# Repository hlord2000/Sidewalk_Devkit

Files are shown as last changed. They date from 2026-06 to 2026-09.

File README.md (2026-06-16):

# Sidewalk Devkit

KiCad hardware design for a compact Nordic Semiconductor devkit built around an
`nRF54L15` target, `nPM1300` power management, and an `SX1262` sub-GHz radio
front end.

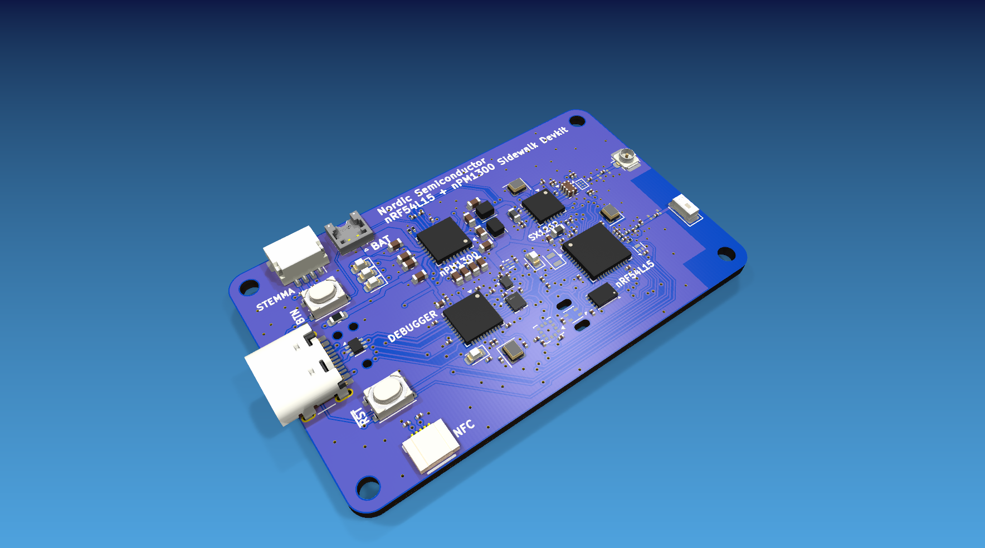
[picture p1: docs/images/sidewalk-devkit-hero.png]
Sidewalk Devkit 3D render


## Hardware

- `nRF54L15-QFAA` target SoC with external `32 MHz` and `32.768 kHz` crystals.
- `nPM1300-QEAA` PMIC for USB/battery power management, charging, and status LEDs.
- `SX1262IMLTRT` sub-GHz transceiver with RF switch/filter network, U.FL, and chip antenna footprints.
- On-board `nRF52833-QDXX` debug helper with USB, SWD, UART, and level-translated target boundary.
- USB-C input with ESD protection and a 1 A fuse.
- Battery connector, reset/user buttons, and board-edge debug/test access.
- `STEMMA QT` I2C expansion connector.
- `SHT4x` humidity/temperature sensor, `ADXL367` accelerometer, and `ZD25WQ16CEIGR` QSPI flash.
- NFC connector footprint and user/status LEDs.

## Board

| Property | Value |
| --- | --- |
| KiCad version | 10.x project files |
| Board revision | `0.1` |
| Size | `55 mm x 34 mm` |
| Stackup | 6 copper layers, 1.6 mm board thickness |
| Minimum track / clearance | `0.127 mm / 0.127 mm` |
| Minimum drill | `0.200 mm` |

## Passed Qualification Tests

- Flashing the `nRF54L15` target from the on-board `nRF52833` debug helper.
- RTT logging.
- UART logging.
- BLE validation.
- NFC validation.
- Sensor and PMIC logging from `SHT40`, `ADXL367`, and `nPM1300`.
- `SX1262` radio operation in both FSK and LoRa modes.
- Sidewalk operation over all transports.

### Top

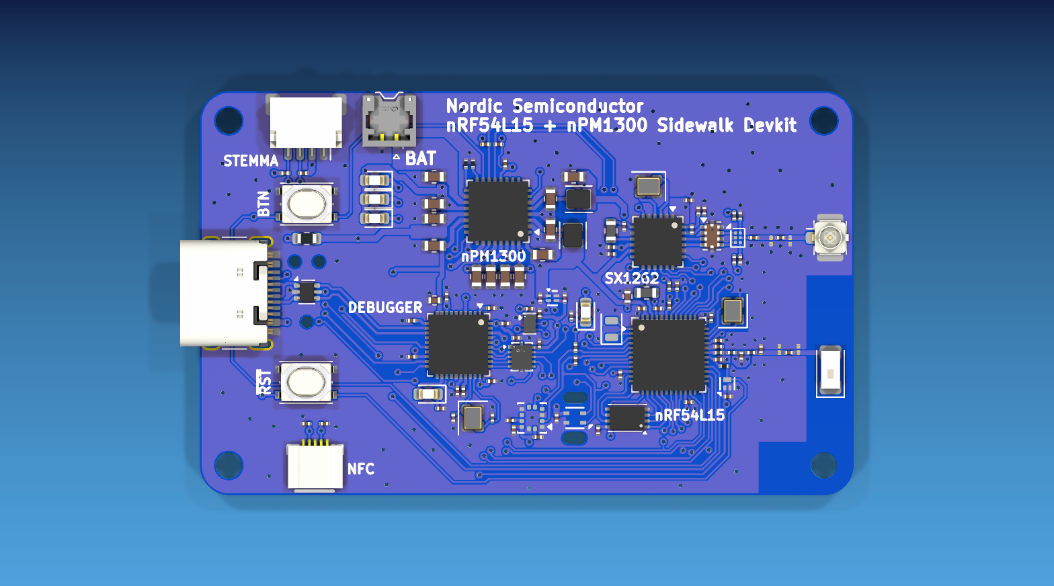
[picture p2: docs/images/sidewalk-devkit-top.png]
Sidewalk Devkit top render


### Bottom

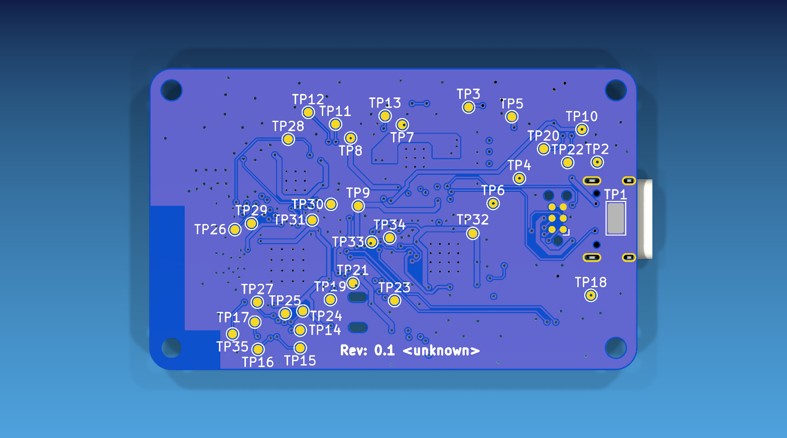
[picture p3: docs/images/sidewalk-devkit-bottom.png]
Sidewalk Devkit bottom render


## Schematic Structure

The design is split into hierarchical KiCad sheets:

- `sch/nRF54L15.kicad_sch` - target SoC, sensors, QSPI flash, STEMMA QT, NFC, and user IO.
- `sch/SX1262.kicad_sch` - sub-GHz radio, RF matching/filtering, antenna switch, and RF connectors.
- `sch/nPM1300.kicad_sch` - USB-C, battery input, PMIC rails, charger support, and PMIC LEDs.
- `sch/Debugger.kicad_sch` - on-board debug helper, target SWD/UART boundary, and level shifting.

## Repository Layout

```text
.
|-- Sidewalk_Devkit.kicad_pro   KiCad project
|-- Sidewalk_Devkit.kicad_sch   Top-level schematic
|-- Sidewalk_Devkit.kicad_pcb   PCB layout
|-- sch/                        Hierarchical schematic sheets
|-- lib/                        Local symbols, footprints, and 3D models
|-- docs/images/                README render images
|-- build/                      Local generated outputs, ignored by git
`-- debug_helper_parts.md       Notes for the debug-helper boundary parts
```

## Regenerating Outputs

The README images are rendered directly from the KiCad PCB:

```bash
mkdir -p docs/images

kicad-cli pcb render Sidewalk_Devkit.kicad_pcb \
  --output docs/images/sidewalk-devkit-hero.png \
  --width 1800 --height 1000 \
  --background opaque --quality high --perspective \
  --rotate '-35,0,35' --zoom 0.84

kicad-cli pcb render Sidewalk_Devkit.kicad_pcb \
  --output docs/images/sidewalk-devkit-top.png \
  --width 1600 --height 900 \
  --side top --background opaque --quality high --zoom 1.12

kicad-cli pcb render Sidewalk_Devkit.kicad_pcb \
  --output docs/images/sidewalk-devkit-bottom.png \
  --width 1600 --height 900 \
  --side bottom --background opaque --quality high --zoom 1.12
```

Useful local exports:

```bash
mkdir -p build

kicad-cli sch export pdf Sidewalk_Devkit.kicad_sch \
  --output build/schematic.pdf

kicad-cli pcb export step Sidewalk_Devkit.kicad_pcb \
  --output build/board.step

kicad-cli sch export bom Sidewalk_Devkit.kicad_sch \
  --output build/bom.csv \
  --fields Reference,Value,Footprint,QUANTITY,DNP \
  --group-by Value,Footprint
```

The custom EasyEDA-derived footprints and 3D models live under `lib/`. STEP
export may still warn if a local KiCad installation does not include every
referenced stock KiCad 3D model.

Run design checks before fabrication or release:

```bash
mkdir -p build
kicad-cli sch erc Sidewalk_Devkit.kicad_sch --output build/erc.rpt
kicad-cli pcb drc Sidewalk_Devkit.kicad_pcb --output build/drc.rpt
```

## License

This hardware design is licensed under the CERN Open Hardware Licence Version 2
- Permissive. See [LICENSE](LICENSE).

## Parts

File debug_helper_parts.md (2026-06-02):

# USB Debug Helper Parts

Date: 2026-05-28

## Chosen MCU

Use `STM32G0B1KBU6`.

- LCSC: `C5159549`
- Package: `UFQFPN-32 5x5`
- Function: USB-powered Zephyr debug helper MCU
- Relevant fit: Zephyr `SOC_STM32G0B1XX`, USB FS from HSI48, UART, enough GPIO for SWD bit-bang
- Parts MCP availability: 325 in stock, extended part, about `$3.02` qty 1 / `$2.55` qty 10

## Target Boundary Interface

Use a `TXU0204RUTR` fixed-direction translator, a dedicated `TXU0101DRYR`
SWDIO output translator, and a switched copy of the target `VTREF`.

SWCLK is one-way helper-to-target. SWDIO is bidirectional at the protocol level,
but this circuit handles it as two one-way legs tied together on the target
side: a target-to-helper read path and a separately enabled helper-to-target
drive path. That matches Zephyr's `dio-gpios`, `dout-gpios`, and `dnoe-gpios`
model.

One `TXU0204` cannot safely do the whole boundary by itself because its single
`OE` would also enable the helper-to-target SWDIO driver during target reads.
Use `TXU0101DRYR` as the independently enabled SWDIO output buffer.

### Recommended Parts

`U_LS_MAIN = TXU0204RUTR`

- LCSC: `C5217875`
- Package: `UQFN-12 1.7x2`
- Quantity: `1`
- Function: dual-supply 4-bit fixed-direction translator, two channels A to B and two channels B to A
- Relevant fit: SWCLK, UART TX, UART RX, and SWDIO read path
- Parts MCP availability: 1354 in stock, extended part, about `$0.90` qty 1 / `$0.78` qty 10

`U_LS_SWDIO_OUT = TXU0101DRYR`

- LCSC: `C5217869`
- Package: `SON-6 1x1.4`
- Quantity: `1`
- Function: dedicated one-channel translator used as a separately enabled SWDIO output buffer
- Relevant fit: helper-driven SWDIO output; high-Z whenever Zephyr's `dnoe-gpios` is inactive
- Parts MCP availability: 242 in stock, extended part, about `$0.50` qty 1 / `$0.43` qty 10

`U_VTREF_SW = TPS22917DBVR`

- LCSC: `C2681320`
- Package: `SOT-23-6`
- Quantity: `1`
- Function: low-leakage load switch for `TARGET_VTREF_NPM` to `VTREF_DBG`
- Relevant fit: 1 V to 5.5 V input, active-high ON, reverse-current blocking, low off current
- Parts MCP availability: 19645 in stock, extended part, about `$0.31` qty 1 / `$0.23` qty 50

`Q_RESET = 2N7002`

- LCSC: `C8545`
- Package: `SOT-23`
- Quantity: `1`
- Function: debugger-controlled open-drain `nRESET` pull-down
- Parts MCP availability: basic part, about 1.63M in stock, about `$0.014` qty 1

## Power And Leakage Rule

The helper and target stay separate power domains.

- `DBG_3V3`: helper-side rail from the helper USB port; powers the STM32 and all translator `VCCA` pins.
- `TARGET_VTREF_NPM`: target IO rail from the nPM1300; do not connect this directly to translator `VCCB`.
- `VTREF_DBG`: switched copy of `TARGET_VTREF_NPM`; powers translator `VCCB` only while helper USB is present and the helper firmware enables the boundary.

Wire `TPS22917DBVR` as:

- `VIN`: `TARGET_VTREF_NPM`
- `VOUT`: `VTREF_DBG`
- `ON`: `DBG_BOUNDARY_EN` from the helper, with about `100 kOhm` pulldown to ground
- `CT`: open, unless a slower `VTREF_DBG` rise is wanted
- `QOD`: connect to `VOUT` for fast `VTREF_DBG` discharge, or leave open for the slowest discharge

When helper USB is unplugged, `DBG_BOUNDARY_EN` is low, `VTREF_DBG` is off, and the target rail is not feeding translator supply current. The remaining target-side current is only pin leakage into unpowered translator I/O plus the load switch off leakage.

Worst-case leakage estimate with helper USB absent:

- `TXU0204` / `TXU0101` Ioff max: `2.5 uA` per A/B pin over `-40 C` to `125 C`
- Target-connected translator pins: `SWCLK`, target `UART_RX`, target `UART_TX`, `SWDIO_IN`, `SWDIO_OUT` = `5` pins
- Translator pin leakage budget: about `12.5 uA` worst case across temperature
- `TPS22917` shutdown current: `250 nA` max to `105 C`; reverse leakage is `1 uA` max
- Add the selected reset MOSFET's off leakage from its own datasheet if reset leakage is critical

Typical leakage should be much lower, but the guaranteed worst-case number is what should be used for battery-life budgeting.

Add local decoupling: `100 nF` from each translator `VCCA` to ground, `100 nF` from each translator `VCCB` to ground, and `100 nF` to `1 uF` on `VTREF_DBG` after the load switch.

## Signal Mapping

Define side A as the STM32 debug helper and side B as the nRF54L15 target.
Helper and target grounds must be common at the debug boundary.

`U_LS_MAIN = TXU0204RUTR`

- `VCCA`: `DBG_3V3`
- `VCCB`: `VTREF_DBG`
- `OE`: `DBG_BOUNDARY_EN`, active high; add about `100 kOhm` pulldown to ground
- `A1 -> B1Y`: `DBG_SWCLK` to `TARGET_SWDCLK`
- `A2 -> B2Y`: `DBG_UART_TX` to `TARGET_UART_RX`
- `B3 -> A3Y`: `TARGET_UART_TX` to `DBG_UART_RX`
- `B4 -> A4Y`: `TARGET_SWDIO` to `DBG_SWDIO_IN`

If `U_LS_MAIN.OE` stays high while Zephyr has the SWD port off, add a weak
pulldown around `100 kOhm` on `DBG_SWCLK` so the target clock does not float.
Firmware should also leave `DBG_SWCLK` low when idle.

`U_LS_SWDIO_OUT = TXU0101DRYR`

- `VCCA`: `DBG_3V3`
- `VCCB`: `VTREF_DBG`
- `A -> BY`: `DBG_SWDIO_OUT` to `TARGET_SWDIO`
- `OE`: `DBG_SWDIO_OE`, active high; add about `100 kOhm` pulldown to ground

The target `SWDIO` node intentionally connects to both `U_LS_MAIN.B4` and
`U_LS_SWDIO_OUT.BY`. `U_LS_MAIN.B4` is only the target-to-helper read path.
`U_LS_SWDIO_OUT.BY` is high-Z except when Zephyr is actively driving SWDIO.

`Q_RESET = 2N7002`

- Drain: `TARGET_nRESET`
- Source: ground
- Gate: `DBG_nRESET_DRIVE_LOW` from the STM32 through about `100 Ohm`
- Gate pulldown: about `100 kOhm` to ground
- Target reset pullup: to the target IO rail, normally about `10 kOhm`

This keeps reset open-drain. When helper USB is unplugged, the MOSFET gate is held low and the target reset pullup does not back-power the helper.

Consider `22` to `47 Ohm` series resistors near the translator outputs on `SWCLK` and `SWDIO_OUT` if routing is longer than a short local connection.

## Zephyr SWDP Notes

Use Zephyr's GPIO SWDP binding with separate SWDIO input and output:

- `clk-gpios`: `DBG_SWCLK`
- `dio-gpios`: `DBG_SWDIO_IN`
- `dout-gpios`: `DBG_SWDIO_OUT`
- `dnoe-gpios`: `DBG_SWDIO_OE` configured as `GPIO_ACTIVE_HIGH`
- `noe-gpios`: omit for the `TXU0204` shared main translator, or use only if you accept that it also gates UART
- `reset-gpios`: `DBG_nRESET_DRIVE_LOW`; choose the GPIO polarity so Zephyr's deasserted reset state drives the NMOS gate physically low
- `keep-reset-deasserted`: include this property if your Zephyr tree has it and you want the driver to actively hold reset released after `swdp_port_off()`

The `dnoe-gpios` name is historical in Zephyr; the driver drives it high while outputting SWDIO and low while reading. That maps directly to the active-high `OE` pin on `TXU0101DRYR`.

If `noe-gpios` is used, the driver drives it logical active while the SWD port is on and logical inactive while off. Do not connect it to `U_LS_MAIN.OE` unless it is acceptable for UART to disappear whenever Zephyr turns the SWD port off.

Reset polarity needs one board-level check because Zephyr trees differ here. With the NMOS reset pull-down above, the safe electrical state is gate low. The `100 kOhm` gate pulldown guarantees that state when helper USB is absent. In firmware, configure the GPIO polarity so Zephyr's deasserted reset state produces a physical low on `DBG_nRESET_DRIVE_LOW`.

## Rejected Shortcut

Do not use a passive or auto-direction level shifter for SWDIO. SWDIO is push-pull and turnaround-sensitive, and Zephyr already supports the explicit `dio-gpios` / `dout-gpios` / `dnoe-gpios` pattern. The `TXU0204` plus `TXU0101` split follows that pattern directly.

`SN74AXC4T774RSVR` is tempting because it is a tiny per-bit-direction translator, but it does not give a separate OE for only the SWDIO output channel. It is less clean with the stock Zephyr SWDP binding than the `TXU0101` output-enable path.

Do not try to use only one `TXU0204` for both SWDIO directions. Its single `OE` would enable the SWDIO output driver during reads and can fight the target.

A second `TXU0204` for `SWDIO_OUT` also works electrically, but it wastes three channels and more board area compared with `TXU0101DRYR`.

## Sources Checked

- Parts MCP: `STM32G0B1KBU6`, `TXU0204RUTR`, `TXU0101DRYR`, `TPS22917DBVR`, `2N7002`, `SN74AXC4T774RSVR`
- Local Zephyr tree: `stm32g0b1` USB/HSI48 support, `zephyr,swdp-gpio` binding, and `swdp_bitbang.c`
- TI TXU0204 / TXU0101 product pages and datasheets: active-high `OE`, 1.08 V to 5.5 V rails, VCC isolation, and Ioff partial-power-down
- TI TPS22917 datasheet/product page: active-high ON, ultra-low shutdown current, and reverse-current blocking

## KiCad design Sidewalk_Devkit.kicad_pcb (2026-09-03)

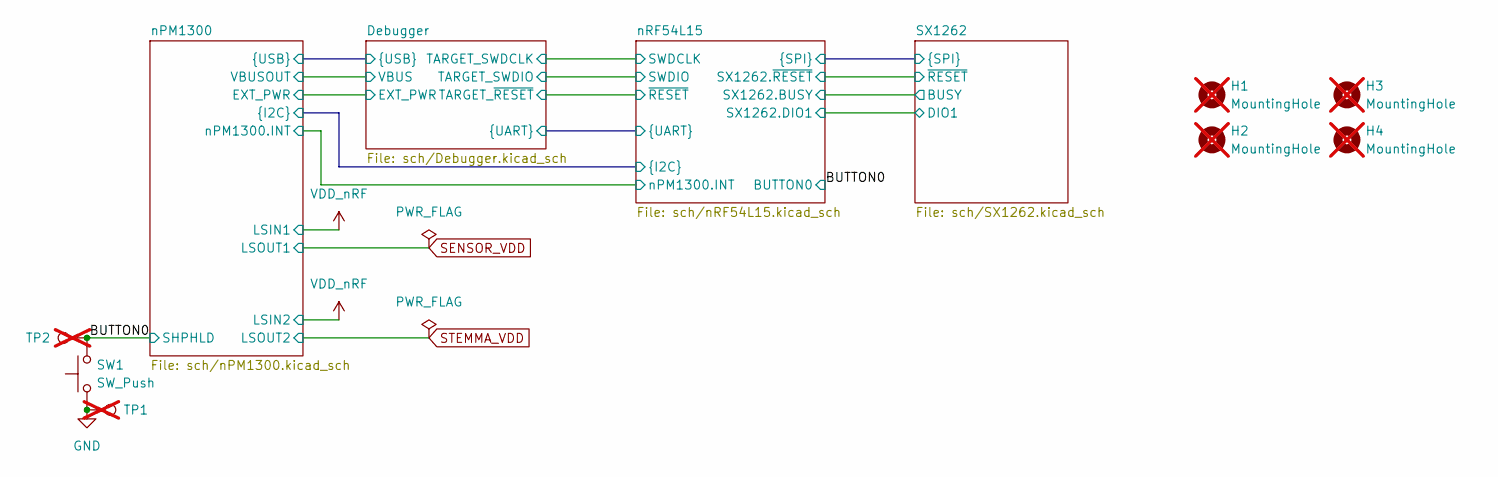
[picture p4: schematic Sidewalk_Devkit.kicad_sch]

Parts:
H1, H2, H3, H4: MountingHole; MountingHole_2.2mm_M2; not fitted
SW1: SW_Push; SW_Push_1P1T_NO_Vertical_Wuerth_434133025816; LCSC C127488
TP1: TestPoint; TestPoint_Keystone_5015_Micro_Mini; not fitted
TP2: TestPoint; TestPoint_Pad_D1.0mm; not fitted

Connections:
/BUTTON0: SW1.2, TP2.1 (1_1); also elsewhere on the board
GND: SW1.1, TP1.1 (1_1); also elsewhere on the board

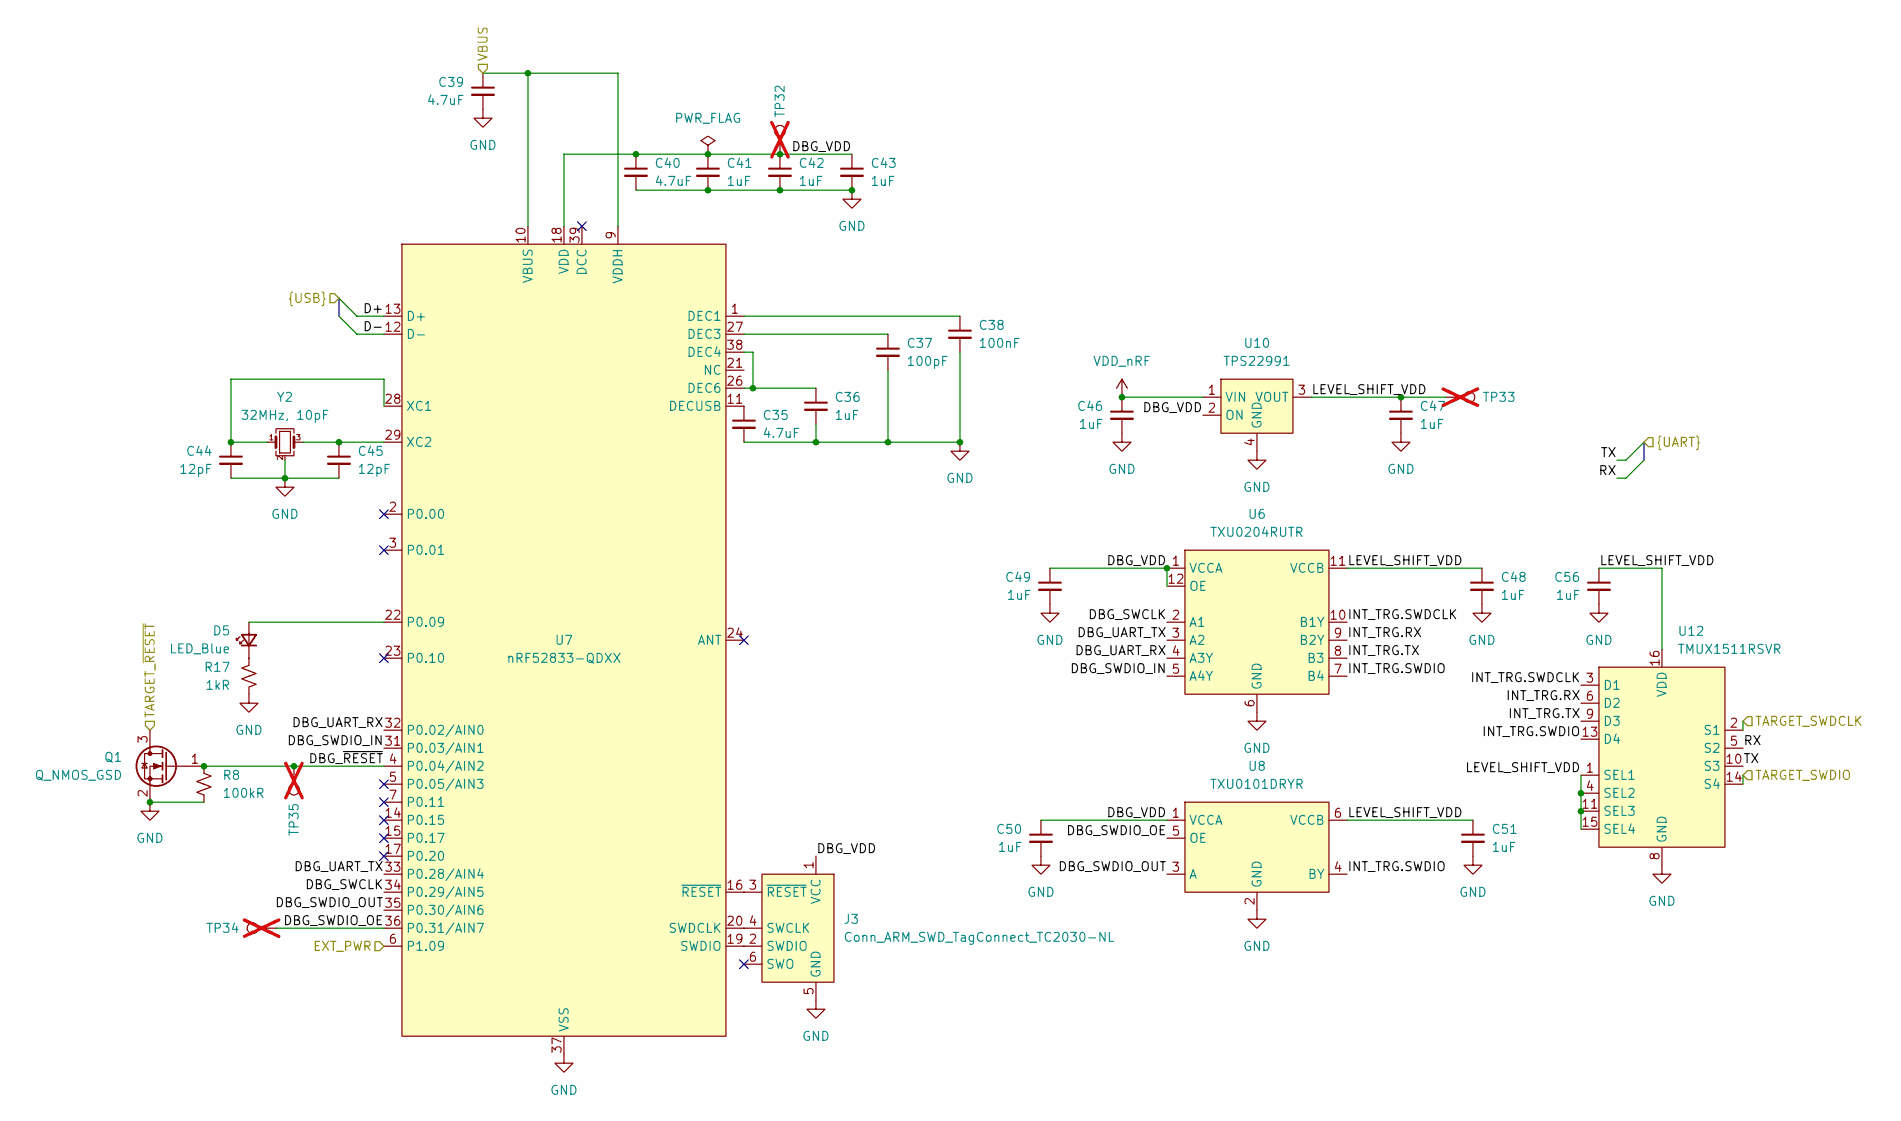
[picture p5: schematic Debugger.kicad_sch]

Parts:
C35, C40: 4.7uF; C_0201_0603Metric_L; LCSC C335103
C36, C41, C42, C43, C46, C47, C48, C49, C50, C51, C56: 1uF; C_0201_0603Metric_L; LCSC C76935
C37: 100pF; C_0201_0603Metric_L; LCSC C62550
C38: 100nF; C_0201_0603Metric_L; LCSC C467016
C39: 4.7uF; C_0402_1005Metric_L; LCSC C23733
C44, C45: 12pF; C_0201_0603Metric_L; LCSC C384960
D5: LED_Blue; LED_0603_1608Metric; LCSC C7496819
J3: Conn_ARM_SWD_TagConnect_TC2030-NL; Tag-Connect_TC2030-IDC-NL_2x03_P1.27mm_Vertical
Q1: Q_NMOS_GSD; Diodes_DFN1006-3; LCSC C19949844
R8: 100kR; C_0201_0603Metric_L; LCSC C106224
R17: 1kR; C_0201_0603Metric_L; LCSC C138165
TP32, TP33, TP34, TP35: TestPoint; TestPoint_Pad_D1.0mm; not fitted
U6: TXU0204RUTR; UQFN-12_L2.0-W1.7-P0.40-TL; MPN TXU0204RUTR; LCSC C5217875
U7: nRF52833-QDXX; QFN-40-1EP_5x5mm_P0.4mm_EP3.6x3.6mm_ThermalVias; LCSC C3007767
U8: TXU0101DRYR; SON-6_L1.5-W1.0-P0.50-TL; MPN TXU0101DRYR; LCSC C5217869
U10: TPS22991; 4-UQFN-0.9x0.8mm; LCSC C49307573
U12: TMUX1511RSVR; UTQFN-16_L2.6-W1.8-P0.40-BL; MPN TMUX1511RSVR; LCSC Part C2673275
Y2: 32MHz, 10pF; Crystal_SMD_2016-4Pin_2.0x1.6mm; LCSC C54427949

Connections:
/Debugger/D+: U7.13 (D+); also elsewhere on the board
/Debugger/D-: U7.12 (D-); also elsewhere on the board
/Debugger/DBG_SWCLK: U6.2 (A1), U7.34 (P0.29/AIN5)
/Debugger/DBG_SWDIO_IN: U6.5 (A4Y), U7.31 (P0.03/AIN1)
/Debugger/DBG_SWDIO_OE: TP34.1 (1_1), U7.36 (P0.31/AIN7), U8.5 (OE)
/Debugger/DBG_SWDIO_OUT: U7.35 (P0.30/AIN6), U8.3 (A)
/Debugger/DBG_UART_RX: U6.4 (A3Y), U7.32 (P0.02/AIN0)
/Debugger/DBG_UART_TX: U6.3 (A2), U7.33 (P0.28/AIN4)
/Debugger/DBG_VDD: C40.1, C41.1, C42.1, C43.1, C49.1, C50.1, J3.1 (VCC), TP32.1 (1_1), U6.1 (VCCA), U6.12 (OE), U7.8 (VDD), U7.18 (VDD), U7.30 (VDD), U7.40 (VDD), U8.1 (VCCA), U10.2 (ON)
/Debugger/DBG_~RESET: Q1.1 (G), R8.1, TP35.1 (1_1), U7.4 (P0.04/AIN2)
/Debugger/EXT_PWR: U7.6 (P1.09); also elsewhere on the board
/Debugger/INT_TRG.RX: U6.9 (B2Y), U12.6 (D2)
/Debugger/INT_TRG.SWDCLK: U6.10 (B1Y), U12.3 (D1)
/Debugger/INT_TRG.SWDIO: U6.7 (B4), U8.4 (BY), U12.13 (D4)
/Debugger/INT_TRG.TX: U6.8 (B3), U12.9 (D3)
/Debugger/LEVEL_SHIFT_VDD: C47.1, C48.1, C51.1, C56.1, TP33.1 (1_1), U6.11 (VCCB), U8.6 (VCCB), U10.3 (VOUT), U12.1 (SEL1), U12.4 (SEL2), U12.11 (SEL3), U12.15 (SEL4), U12.16 (VDD)
/Debugger/RX: U12.5 (S2); also elsewhere on the board
/Debugger/TARGET_SWDCLK: U12.2 (S1); also elsewhere on the board
/Debugger/TARGET_SWDIO: U12.14 (S4); also elsewhere on the board
/Debugger/TARGET_~RESET: Q1.3 (D); also elsewhere on the board
/Debugger/TX: U12.10 (S3); also elsewhere on the board
/Debugger/VBUS: C39.1, U7.9 (VDDH), U7.10 (VBUS); also elsewhere on the board
GND: C35.2, C36.2, C37.2, C38.2, C39.2, C40.2, C41.2, C42.2, C43.2, C44.2, C45.2, C46.2, C47.2, C48.2, C49.2, C50.2, C51.2, C56.2, J3.5 (GND), Q1.2 (S), R8.2, R17.2, U6.6 (GND), U7.25 (VSS_PA), U7.37 (VSS), U7.41 (VSS), U8.2 (GND), U10.4 (GND), U12.8 (GND), Y2.2 (G), Y2.4 (G); also elsewhere on the board
unnamed: D5.2 (A), U7.22 (P0.09)
unnamed: D5.1 (K), R17.1
unnamed: J3.4 (SWCLK), U7.20 (SWDCLK)
unnamed: J3.2 (SWDIO), U7.19 (SWDIO)
unnamed: J3.3 (~RESET), U7.16 (~RESET)
unnamed: C38.1, U7.1 (DEC1)
unnamed: C37.1, U7.27 (DEC3)
unnamed: C36.1, U7.26 (DEC6), U7.38 (DEC4)
unnamed: C35.1, U7.11 (DECUSB)
unnamed: C44.1, U7.28 (XC1), Y2.1
unnamed: C45.1, U7.29 (XC2), Y2.3
VDD_nRF: C46.1, U10.1 (VIN); also elsewhere on the board

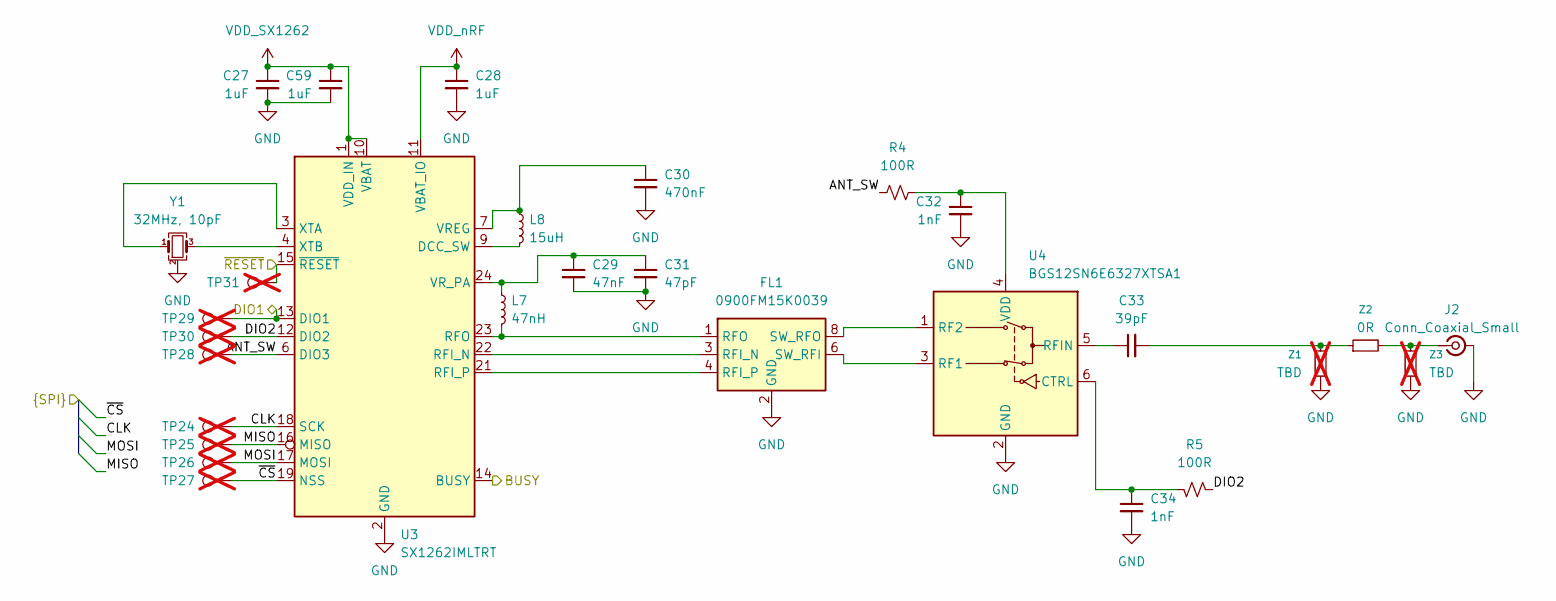
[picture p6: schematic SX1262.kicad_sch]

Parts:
C27, C28, C59: 1uF; C_0201_0603Metric_L; LCSC C76935
C29: 47nF; C_0201_0603Metric_L; LCSC C88917
C30: 470nF; C_0201_0603Metric_L; LCSC C85926
C31: 47pF; C_0201_0603Metric_L; LCSC C62546
C32, C34: 1nF; C_0201_0603Metric_L; LCSC C66942
C33: 39pF; C_0201_0603Metric_L; LCSC C85904
FL1: 0900FM15K0039; Balun_Johanson_0900FM15K0039; LCSC C7434807
J2: Conn_Coaxial_Small; U.FL_Hirose_U.FL-R-SMT-1_Vertical; LCSC C88374
L7: 47nH; L_0201_0603Metric_L; LCSC C1857885
L8: 15uH; L_0603_1608Metric_L; LCSC C2838019
R4, R5: 100R; C_0201_0603Metric_L; LCSC C77623
TP24, TP25, TP26, TP27, TP28, TP29, TP30, TP31: TestPoint; TestPoint_Pad_D1.0mm; not fitted
U3: SX1262IMLTRT; QFN-24-1EP_4x4mm_P0.5mm_EP2.6x2.6mm_ThermalVias; LCSC C191341
U4: BGS12SN6E6327XTSA1; Infineon_PG-TSNP-6-10_0.7x1.1mm_0.7x1.1mm_P0.4mm; LCSC C114953
Y1: 32MHz, 10pF; Crystal_SMD_2016-4Pin_2.0x1.6mm; LCSC C1986260
Z1, Z3: TBD; C_0201_0603Metric_L; not fitted
Z2: 0R; C_0201_0603Metric_L; LCSC C473473

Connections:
/SX1262/ANT_SW: R4.1, TP28.1 (1_1), U3.6 (DIO3)
/SX1262/BUSY: U3.14 (BUSY); also elsewhere on the board
/SX1262/CLK: TP24.1 (1_1), U3.18 (SCK); also elsewhere on the board
/SX1262/DIO1: TP29.1 (1_1), U3.13 (DIO1); also elsewhere on the board
/SX1262/DIO2: R5.1, TP30.1 (1_1), U3.12 (DIO2)
/SX1262/MISO: TP25.1 (1_1), U3.16 (MISO); also elsewhere on the board
/SX1262/MOSI: TP26.1 (1_1), U3.17 (MOSI); also elsewhere on the board
/SX1262/~CS: TP27.1 (1_1), U3.19 (NSS); also elsewhere on the board
/SX1262/~RESET: TP31.1 (1_1), U3.15 (~RESET); also elsewhere on the board
GND: C27.2, C28.2, C29.2, C30.2, C31.2, C32.2, C34.2, C59.2, FL1.2 (GND), FL1.5 (GND), FL1.7 (GND), FL1.9 (GND), FL1.10 (GND), J2.2 (Ext), U3.2 (GND), U3.5 (GND), U3.8 (GND), U3.20 (GND), U3.25 (GND), U4.2 (GND), Y1.2 (G), Y1.4 (G), Z1.1, Z3.1; also elsewhere on the board
unnamed: C33.2, Z1.2, Z2.1
unnamed: FL1.3 (RFI_N), U3.22 (RFI_N)
unnamed: FL1.4 (RFI_P), U3.21 (RFI_P)
unnamed: FL1.1 (RFO), L7.2, U3.23 (RFO)
unnamed: FL1.6 (SW_RFI), U4.3 (RF1)
unnamed: FL1.8 (SW_RFO), U4.1 (RF2)
unnamed: J2.1 (In), Z2.2, Z3.2
unnamed: L8.2, U3.9 (DCC_SW)
unnamed: C30.1, L8.1, U3.7 (VREG)
unnamed: C29.1, C31.1, L7.1, U3.24 (VR_PA)
unnamed: U3.3 (XTA), Y1.1
unnamed: U3.4 (XTB), Y1.3
unnamed: C34.1, R5.2, U4.6 (CTRL)
unnamed: C33.1, U4.5 (RFIN)
unnamed: C32.1, R4.2, U4.4 (VDD)
VDD_SX1262: C27.1, C59.1, U3.1 (VDD_IN), U3.10 (VBAT); also elsewhere on the board
VDD_nRF: C28.1, U3.11 (VBAT_IO); also elsewhere on the board

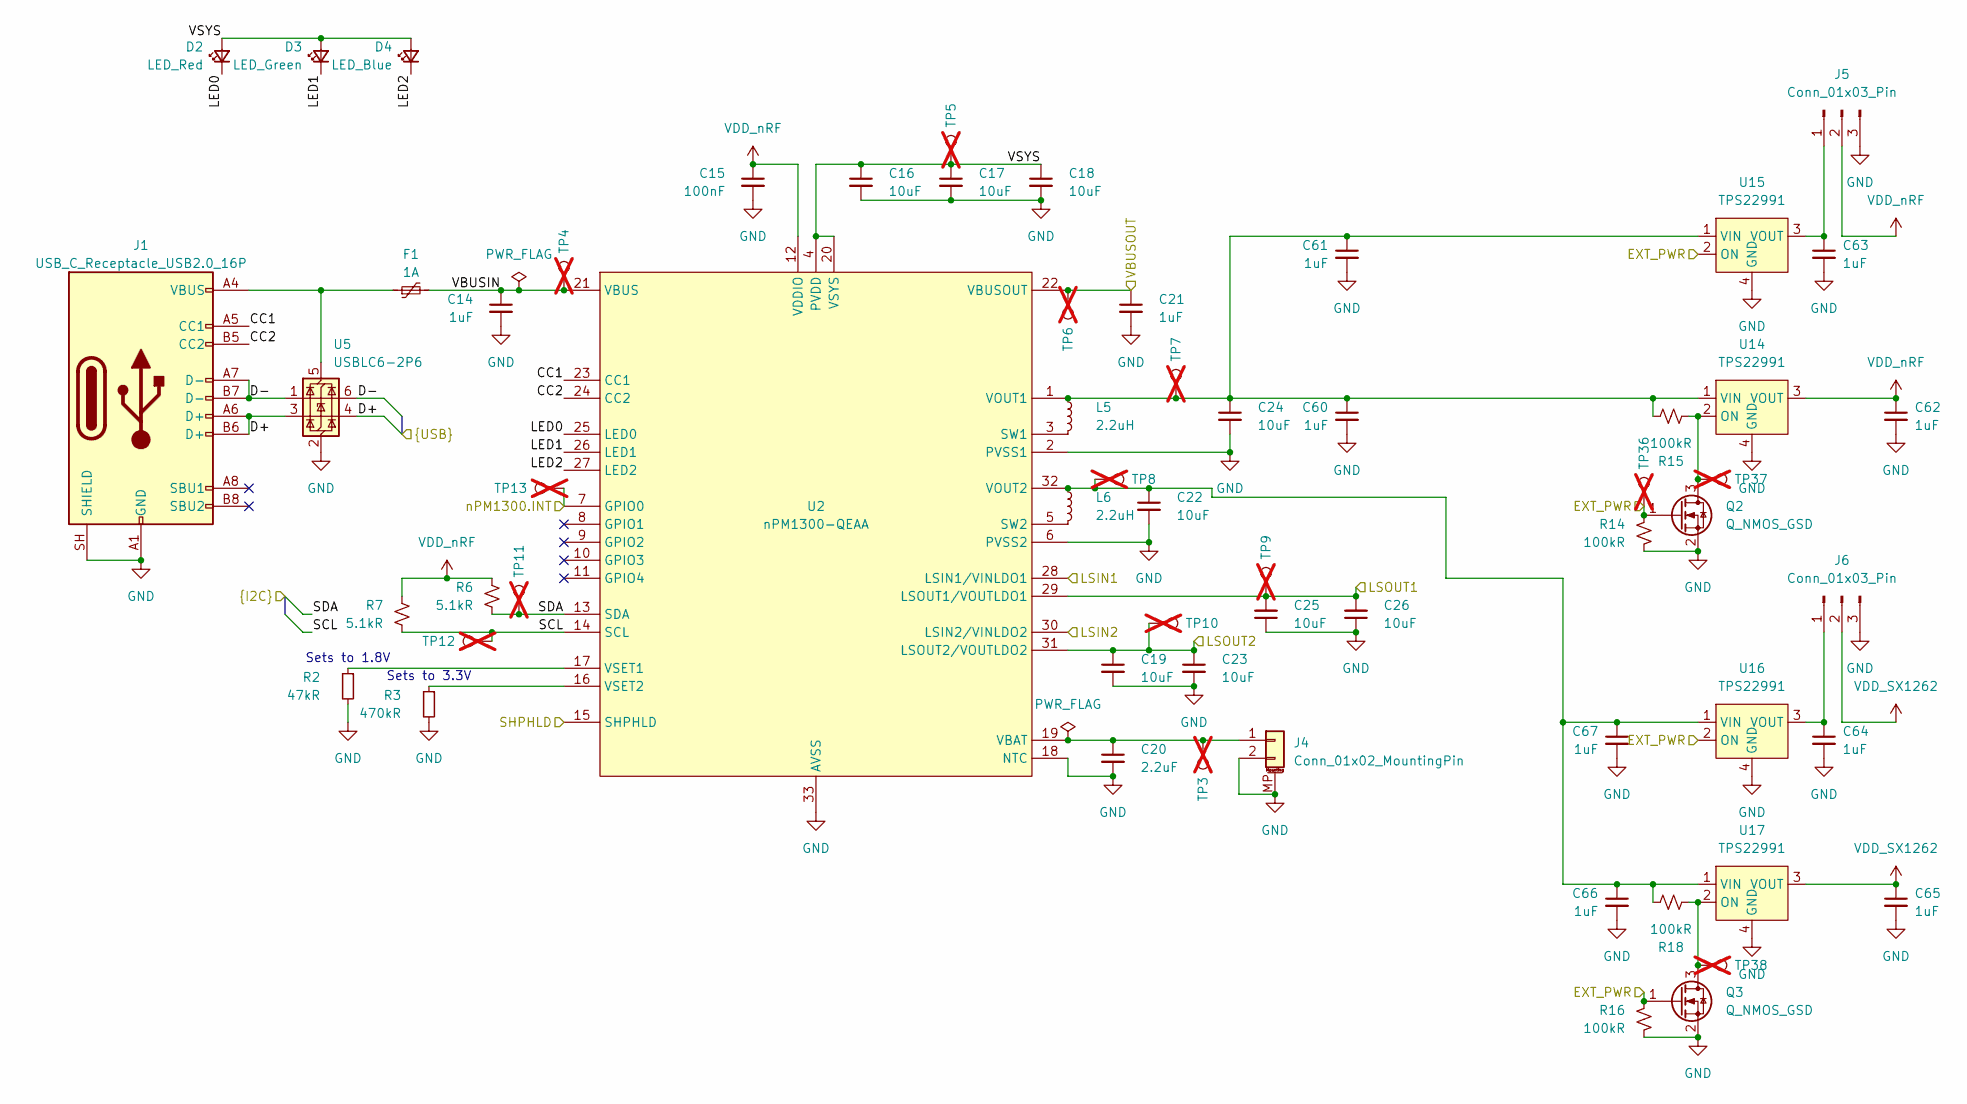
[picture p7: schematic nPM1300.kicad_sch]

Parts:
C14, C21: 1uF; C_0603_1608Metric_L; LCSC C15849
C15: 100nF; C_0201_0603Metric_L; LCSC C467016
C16, C17, C18, C19, C22, C23, C24, C25, C26: 10uF; C_0603_1608Metric_L; LCSC C19702
C20: 2.2uF; C_0603_1608Metric_L; LCSC C23630
C60, C61, C62, C63, C64, C65, C66, C67: 1uF; C_0201_0603Metric_L; LCSC C76935
D2: LED_Red; LED_0603_1608Metric; LCSC C2286
D3: LED_Green; LED_0603_1608Metric; LCSC C19189745
D4: LED_Blue; LED_0603_1608Metric; LCSC C965807
F1: 1A; Fuse_0603_1608Metric; LCSC C516069
J1: USB_C_Receptacle_USB2.0_16P; USB_C_Receptacle_HRO_TYPE-C-31-M-12-Edge_Silkscreen_Removed; LCSC C165948
J4: Conn_01x02_MountingPin; JST_ACH_BM02B-ACHSS-GAN-ETF_1x02-1MP_P1.20mm_Vertical; LCSC C5118738
J5, J6: Conn_01x03_Pin; PinHeader_1x03_P2.54mm_Vertical
L5, L6: 2.2uH; L_0806_2016Metric_L; LCSC C412023
Q2, Q3: Q_NMOS_GSD; Diodes_DFN1006-3; LCSC C19949844
R2: 47kR; R_0201_0603Metric_L; LCSC C138139
R3: 470kR; R_0201_0603Metric_L; LCSC C274343
R6, R7: 5.1kR; C_0201_0603Metric_L; LCSC C270344
R14, R15, R16, R18: 100kR; C_0201_0603Metric_L; LCSC C106224
TP3, TP4, TP5, TP6, TP7, TP8, TP9, TP10, TP11, TP12, TP13, TP36, TP37, TP38: TestPoint; TestPoint_Pad_D1.0mm; not fitted
U2: nPM1300-QEAA; QFN-32-1EP_5x5mm_P0.5mm_EP3.6x3.6mm_ThermalVias; LCSC C30627544
U5: USBLC6-2P6; SOT-666; LCSC C15999
U14, U15, U16, U17: TPS22991; 4-UQFN-0.9x0.8mm; LCSC C49307573

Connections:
/BUTTON0: U2.15 (SHPHLD); also elsewhere on the board
/Debugger/D+: J1.A6 (D+), J1.B6 (D+), U5.3 (I/O2), U5.4 (I/O2); also elsewhere on the board
/Debugger/D-: J1.A7 (D-), J1.B7 (D-), U5.1 (I/O1), U5.6 (I/O1); also elsewhere on the board
/Debugger/EXT_PWR: Q2.1 (G), Q3.1 (G), R14.1, R16.1, TP36.1 (1_1), U15.2 (ON), U16.2 (ON); also elsewhere on the board
/Debugger/VBUS: C21.1, TP6.1 (1_1), U2.22 (VBUSOUT); also elsewhere on the board
/nPM1300/CC1: J1.A5 (CC1), U2.23 (CC1)
/nPM1300/CC2: J1.B5 (CC2), U2.24 (CC2)
/nPM1300/LED0: D2.1 (K), U2.25 (LED0)
/nPM1300/LED1: D3.1 (K), U2.26 (LED1)
/nPM1300/LED2: D4.1 (K), U2.27 (LED2)
/nPM1300/SCL: R7.2, TP12.1 (1_1), U2.14 (SCL); also elsewhere on the board
/nPM1300/SDA: R6.2, TP11.1 (1_1), U2.13 (SDA); also elsewhere on the board
/nPM1300/VBUSIN: C14.1, F1.2, TP4.1 (1_1), U2.21 (VBUS)
/nPM1300/VSYS: C16.1, C17.1, C18.1, D2.2 (A), D3.2 (A), D4.2 (A), TP5.1 (1_1), U2.4 (PVDD), U2.20 (VSYS)
/nPM1300/nPM1300.INT: TP13.1 (1_1), U2.7 (GPIO0); also elsewhere on the board
GND: C14.2, C15.2, C16.2, C17.2, C18.2, C19.2, C20.2, C21.2, C22.2, C23.2, C24.2, C25.1, C26.1, C60.2, C61.2, C62.2, C63.2, C64.2, C65.2, C66.2, C67.2, J1.A1 (GND), J1.A12 (GND), J1.B1 (GND), J1.B12 (GND), J1.SH (SHIELD), J4.2, J4.MP (MountPin), J5.3, J6.3, Q2.2 (S), Q3.2 (S), R2.2, R3.2, R14.2, R16.2, U2.2 (PVSS1), U2.6 (PVSS2), U2.18 (NTC), U2.33 (AVSS), U5.2 (GND), U14.4 (GND), U15.4 (GND), U16.4 (GND), U17.4 (GND); also elsewhere on the board
unnamed: C20.1, J4.1, TP3.1 (1_1), U2.19 (VBAT)
unnamed: C63.1, J5.1, U15.3 (VOUT)
unnamed: C64.1, J6.1, U16.3 (VOUT)
unnamed: Q2.3 (D), R15.2, TP37.1 (1_1), U14.2 (ON)
unnamed: Q3.3 (D), R18.2, TP38.1 (1_1), U17.2 (ON)
unnamed: L5.2, U2.3 (SW1)
unnamed: L6.1, U2.5 (SW2)
unnamed: R2.1, U2.17 (VSET1)
unnamed: R3.1, U2.16 (VSET2)
unnamed: F1.1, J1.A4 (VBUS), J1.A9 (VBUS), J1.B4 (VBUS), J1.B9 (VBUS), U5.5 (VBUS)
unnamed: C24.1, C60.1, C61.1, L5.1, R15.1, TP7.1 (1_1), U2.1 (VOUT1), U14.1 (VIN), U15.1 (VIN)
unnamed: C22.1, C66.1, C67.1, L6.2, R18.1, TP8.1 (1_1), U2.32 (VOUT2), U16.1 (VIN), U17.1 (VIN)
SENSOR_VDD: C25.2, C26.2, TP9.1 (1_1), U2.29 (LSOUT1/VOUTLDO1); also elsewhere on the board
STEMMA_VDD: C19.1, C23.1, TP10.1 (1_1), U2.31 (LSOUT2/VOUTLDO2); also elsewhere on the board
VDD_SX1262: C65.1, J6.2, U17.3 (VOUT); also elsewhere on the board
VDD_nRF: C15.1, C62.1, J5.2, R6.1, R7.1, U2.12 (VDDIO), U2.28 (LSIN1/VINLDO1), U2.30 (LSIN2/VINLDO2), U14.3 (VOUT); also elsewhere on the board

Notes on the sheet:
Sets to 1.8V
Sets to 3.3V

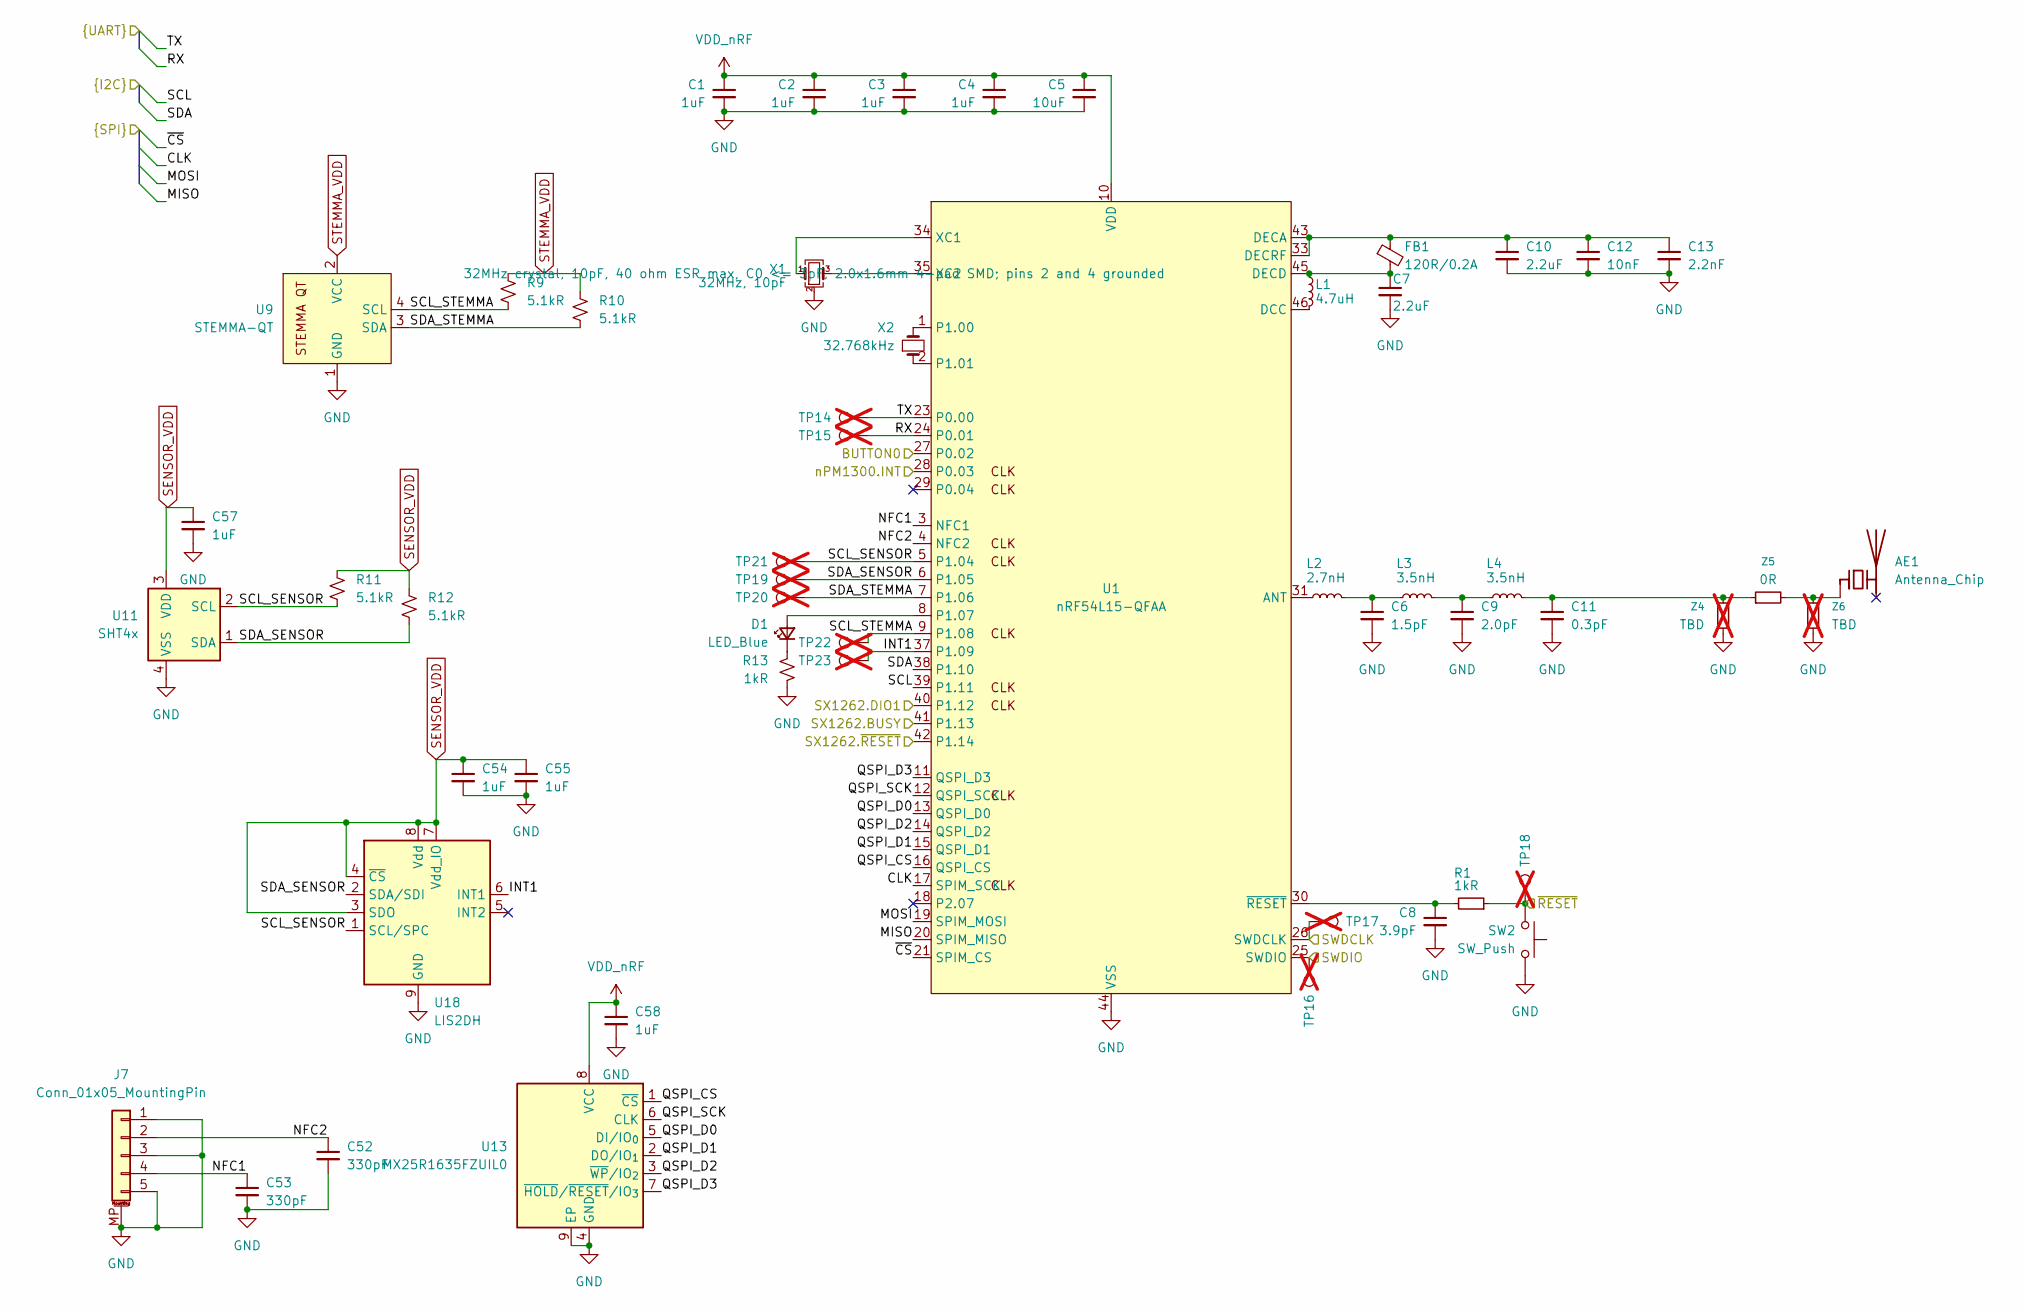
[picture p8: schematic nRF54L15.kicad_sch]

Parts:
AE1: Antenna_Chip; Johanson_2450AT18x100; LCSC C89334
C1, C2, C3, C4, C54, C55, C57, C58: 1uF; C_0201_0603Metric_L; LCSC C76935
C5: 10uF; C_0402_1005Metric_L; LCSC C15525
C6: 1.5pF; C_0201_0603Metric_L; LCSC C161414
C7, C10: 2.2uF; C_0201_0603Metric_L; LCSC C319184
C8: 3.9pF; C_0201_0603Metric_L; LCSC C76926
C9: 2.0pF; C_0201_0603Metric_L; LCSC C161419
C11: 0.3pF; C_0201_0603Metric_L; LCSC C161289
C12: 10nF; C_0201_0603Metric_L; LCSC C5142551
C13: 2.2nF; C_0201_0603Metric_L; LCSC C80433
C52, C53: 330pF; C_0201_0603Metric_L; LCSC C237559
D1: LED_Blue; LED_0603_1608Metric; LCSC C7496819
FB1: 120R/0.2A; L_0201_0603Metric_L; LCSC C97850
J7: Conn_01x05_MountingPin; CONN-SMD_5P-P0.50_0.5K-1.2W-5PWB; LCSC C5337029
L1: 4.7uH; L_0603_1608Metric_L; LCSC C48944999
L2: 2.7nH; L_0201_0603Metric_L; LCSC C7216765
L3, L4: 3.5nH; L_0201_0603Metric_L; LCSC C3911055
R1: 1kR; R_0201_0603Metric_L; LCSC C138165
R9, R10, R11, R12: 5.1kR; C_0201_0603Metric_L; LCSC C270344
R13: 1kR; C_0201_0603Metric_L; LCSC C138165
SW2: SW_Push; SW_Push_1P1T_NO_Vertical_Wuerth_434133025816; LCSC C127488
TP14, TP15, TP16, TP17, TP18, TP19, TP20, TP21, TP22, TP23: TestPoint; TestPoint_Pad_D1.0mm; not fitted
U1: nRF54L15-QFAA; QFN-48-1EP_6x6mm_P0.4mm_EP4.6x4.6mm_ThermalVias; LCSC C42458750
U9: STEMMA-QT; JST_SH_SM04B-SRSS-TB_1x04-1MP_P1.00mm_Horizontal; LCSC C160404
U11: SHT4x; Sensirion_DFN-4_1.5x1.5mm_P0.8mm_SHT4x_NoCentralPad; LCSC C2848306
U13: MX25R1635FZUIL0; Winbond_USON-8-1EP_3x2mm_P0.5mm_EP0.2x1.6mm; LCSC C152595
U18: LIS2DH; LGA-14_2x2mm_P0.35mm_LayoutBorder3x4y; LCSC C110926
X1: 32MHz, 10pF; Crystal_SMD_2016-4Pin_2.0x1.6mm; LCSC C54427949
X2: 32.768kHz; Crystal_SMD_2012-2Pin_2.0x1.2mm; LCSC C99009
Z4, Z6: TBD; C_0201_0603Metric_L; not fitted
Z5: 0R; C_0201_0603Metric_L; LCSC C473473

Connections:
/BUTTON0: U1.27 (P0.02); also elsewhere on the board
/Debugger/RX: TP15.1 (1_1), U1.24 (P0.01); also elsewhere on the board
/Debugger/TARGET_SWDCLK: TP17.1 (1_1), U1.26 (SWDCLK); also elsewhere on the board
/Debugger/TARGET_SWDIO: TP16.1 (1_1), U1.25 (SWDIO); also elsewhere on the board
/Debugger/TARGET_~RESET: R1.1, SW2.2, TP18.1 (1_1); also elsewhere on the board
/Debugger/TX: TP14.1 (1_1), U1.23 (P0.00); also elsewhere on the board
/SX1262/BUSY: U1.41 (P1.13); also elsewhere on the board
/SX1262/CLK: U1.17 (SPIM_SCK); also elsewhere on the board
/SX1262/DIO1: U1.40 (P1.12); also elsewhere on the board
/SX1262/MISO: U1.20 (SPIM_MISO); also elsewhere on the board
/SX1262/MOSI: U1.19 (SPIM_MOSI); also elsewhere on the board
/SX1262/~CS: U1.21 (SPIM_CS); also elsewhere on the board
/SX1262/~RESET: U1.42 (P1.14); also elsewhere on the board
/nPM1300/SCL: U1.39 (P1.11); also elsewhere on the board
/nPM1300/SDA: U1.38 (P1.10); also elsewhere on the board
/nPM1300/nPM1300.INT: U1.28 (P0.03); also elsewhere on the board
/nRF54L15/INT1: TP23.1 (1_1), U1.37 (P1.09), U18.6 (INT1)
/nRF54L15/NFC1: C53.1, J7.4, U1.3 (NFC1)
/nRF54L15/NFC2: C52.1, J7.2, U1.4 (NFC2)
/nRF54L15/QSPI_CS: U1.16 (QSPI_CS), U13.1 (~CS)
/nRF54L15/QSPI_D0: U1.13 (QSPI_D0), U13.5 (DI/IO_{0})
/nRF54L15/QSPI_D1: U1.15 (QSPI_D1), U13.2 (DO/IO_{1})
/nRF54L15/QSPI_D2: U1.14 (QSPI_D2), U13.3 (~WP/IO_{2})
/nRF54L15/QSPI_D3: U1.11 (QSPI_D3), U13.7 (~HOLD/~RESET/IO_{3})
/nRF54L15/QSPI_SCK: U1.12 (QSPI_SCK), U13.6 (CLK)
/nRF54L15/SCL_SENSOR: R11.2, TP21.1 (1_1), U1.5 (P1.04), U11.2 (SCL), U18.1 (SCL/SPC)
/nRF54L15/SCL_STEMMA: R9.2, TP22.1 (1_1), U1.9 (P1.08), U9.4 (SCL)
/nRF54L15/SDA_SENSOR: R12.2, TP19.1 (1_1), U1.6 (P1.05), U11.1 (SDA), U18.2 (SDA/SDI)
/nRF54L15/SDA_STEMMA: R10.2, TP20.1 (1_1), U1.7 (P1.06), U9.3 (SDA)
GND: C1.2, C2.2, C3.2, C4.2, C5.2, C6.2, C7.2, C8.2, C9.2, C10.2, C11.2, C12.2, C13.2, C52.2, C53.2, C54.2, C55.2, C57.2, C58.2, J7.1, J7.3, J7.5, J7.MP (MountPin), R13.2, SW2.1, U1.32 (VSS_PA), U1.44 (VSS), U1.49 (VSS), U9.1 (GND), U9.MP (GND), U11.4 (VSS), U13.4 (GND), U13.9 (EP), U18.9 (GND), U18.10 (GND), U18.11 (GND), U18.12 (GND), U18.13 (GND), U18.14 (GND), X1.2 (G), X1.4 (G), Z4.1, Z6.1; also elsewhere on the board
unnamed: AE1.1 (FEED_1), Z5.2, Z6.2
unnamed: C6.1, L2.2, L3.1
unnamed: C9.1, L3.2, L4.1
unnamed: C11.1, L4.2, Z4.2, Z5.1
unnamed: D1.2 (A), U1.8 (P1.07)
unnamed: D1.1 (K), R13.1
unnamed: L2.1, U1.31 (ANT)
unnamed: L1.2, U1.46 (DCC)
unnamed: C10.1, C12.1, C13.1, FB1.1, U1.33 (DECRF), U1.43 (DECA)
unnamed: C7.1, FB1.2, L1.1, U1.45 (DECD)
unnamed: U1.1 (P1.00), X2.2
unnamed: U1.2 (P1.01), X2.1
unnamed: U1.34 (XC1), X1.1
unnamed: U1.35 (XC2), X1.3
unnamed: C8.1, R1.2, U1.30 (~RESET)
SENSOR_VDD: C54.1, C55.1, C57.1, R11.1, R12.1, U11.3 (VDD), U18.3 (SDO), U18.4 (~CS), U18.7 (Vdd_IO), U18.8 (Vdd); also elsewhere on the board
STEMMA_VDD: R9.1, R10.1, U9.2 (VCC); also elsewhere on the board
VDD_nRF: C1.1, C2.1, C3.1, C4.1, C5.1, C58.1, U1.10 (VDD), U1.22 (VDD), U1.36 (VDD), U1.47 (VDD), U1.48 (VDD), U13.8 (VCC); also elsewhere on the board

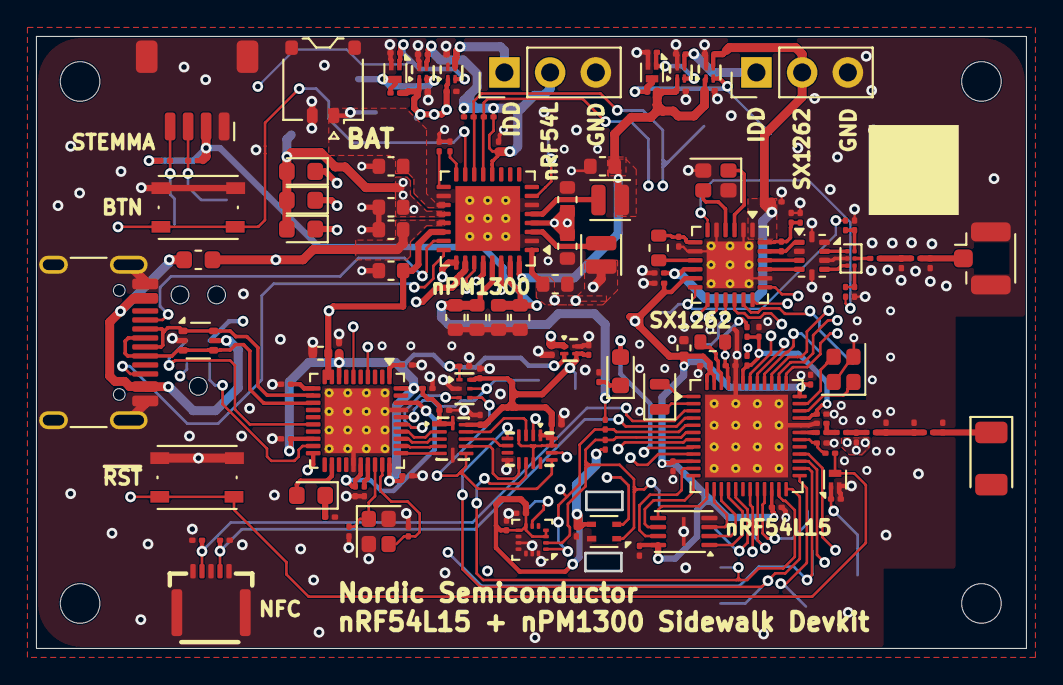
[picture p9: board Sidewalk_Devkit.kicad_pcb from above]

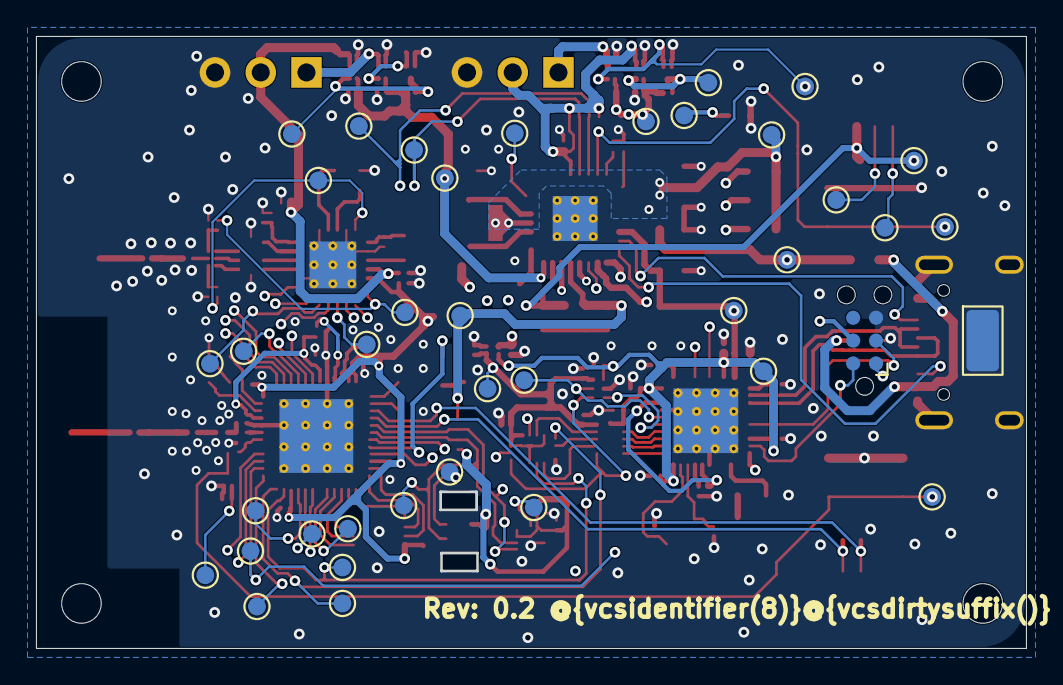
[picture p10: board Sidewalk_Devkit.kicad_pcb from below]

Board: 6 copper layers, 55.0 x 34.0 mm, 184 parts (39 on the bottom side), 113 nets.

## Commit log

2026-06-02 Initial commit.
    [Debugger.kicad_sch, SX1262.kicad_sch, Sidewalk_Devkit.kicad_pcb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]
2026-06-02 Updates for rev 1
    [Debugger.kicad_sch, SX1262.kicad_sch, Sidewalk_Devkit.kicad_pcb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]
2026-06-16 Add missing 3D models
    [SX1262.kicad_sch, Sidewalk_Devkit.kicad_pcb]
2026-06-16 Add board PDFs
2026-06-18 Added external current measurement for L15 and SX1262
    [Debugger.kicad_sch, Sidewalk_Devkit.kicad_pcb, Sidewalk_Devkit.kicad_sch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]
2026-08-05 Revision 0.2
    [Debugger.kicad_sch, SX1262.kicad_sch, Sidewalk_Devkit.kicad_pcb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]
2026-08-06 Added QR code area
    [Sidewalk_Devkit.kicad_pcb]
2026-09-03 Updates for V2
    [Debugger.kicad_sch, SX1262.kicad_sch, Sidewalk_Devkit.kicad_pcb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]
